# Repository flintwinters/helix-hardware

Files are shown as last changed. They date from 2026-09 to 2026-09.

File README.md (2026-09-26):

# Helix minimal hardware slice

KiCad 10 schematic for a USB powered STM32C071FBP6 with one shared SPI bus. The WIZ850io W5500 module and a **3.3 V, six wire microSD SPI breakout** have separate chip selects. SWD is available for first firmware bring-up.

Open `helix_minimal.kicad_pro` in KiCad. Run `python3 manage.py check` for label lint, ERC, and critical nets, or `python3 manage.py audit` for full DRC and every PCB pad net. The [PCB audit](docs/pcb_audit.md) records datasheet mappings and remaining risks. `python3 manage.py repair` fixes misplaced component reference/value fields in the existing schematic without rebuilding it. `python3 manage.py build` creates a schematic only when none exists. Building needs the KiCad 10 symbol library (`KICAD_SYMBOL_DIR` can point to it); the checked-in schematic and local symbols are self-contained.

## PCB routing

The PCB uses pinned [KiCadRoutingTools](https://github.com/drandyhaas/KiCadRoutingTools) (`git submodule update --init`). USB D+/D− were routed manually; the other signals were autorouted around them. Board Setup specifies 0.30 mm tracks and 0.20 mm clearance for ordinary nets. The USB connector class uses 0.15 mm tracks and clearance for USB D±, CC1/CC2, and VBUS; cross-class clearance is 0.20 mm. GND has F.Cu and B.Cu pours, with no GND tracks or vias. Both pours use thermal reliefs by default: in KiCad's [zone format](https://dev-docs.kicad.org/en/file-formats/sexpr-intro/index.html), omitting the `connect_pads` mode selects thermal reliefs, while `yes` selects solid connections. The four mounting-hole pads remain solid for mechanical grounding. Seven crowded GND pads use explicit solid connections because thermal reliefs there left only one spoke and failed DRC.

After manually connecting `/USB_DP` and `/USB_DM`, run `python3 manage.py route` on a preserved board. It removes other top-level tracks and vias from a working copy while retaining the manual USB copper, footprints, and both GND zones. It refuses to start until both USB data nets have copper, excludes them and GND from every autorouter net list, and verifies that their copper geometry survives the route. It routes CC1/CC2/VBUS first at 0.15 mm width, then SWCLK and the other ordinary nets at 0.30/0.20 mm. The USB pass omits `--clearance` so the router honors the 0.20 mm clearance against ordinary nets. It force-reroutes SPI MISO at 0.30 mm to remove the router's multipoint narrow taper, then force-reroutes +3V3 to remove a dangling via observed in the earlier 4000 turn-cost run. All passes use `--via-cost 300 --turn-cost 4000 --heuristic-weight 1.0 --same-net-pad-clearance 0.1 --grid-step 0.05 --via-size 0.4 --via-drill 0.2 --escalation off --strict-sizes --no-fix-drc-settings`. The router tries direction-preference costs 1200 and 2000 (F.Cu horizontal, B.Cu vertical), then installs the completed route with the smallest sum of squared non-USB net lengths plus an off-axis penalty. The original and intermediate boards remain in `.recovery/`. This is candidate selection; the pinned Rust A* search itself has no quadratic-length parameter. Run `python3 manage.py audit` after routing.

KiCad DRC reports no signal routing or thermal-relief violations and zero schematic parity issues. Two GND connections remain for manual review; 18 text-height warnings remain. The WIZ850io module body overlaps H3, R3, and R4 in a mechanical courtyard probe; resolve its assembly height and mechanical clearance before fabrication. J6 has SWCLK where an SPI accessory would need SCK.

The current route uses a 4000 turn cost and direction-preference cost 2000. All 24 manually drawn USB data copper items were preserved exactly. Its input and intermediate boards are recoverable in `.recovery/` if needed.

## Interfaces

| Interface | STM32 pads | Connector pins |
| --- | --- | --- |
| SPI1 SCK / MISO / MOSI | PA5 / PA6 / PA7 | WIZ850io U3.4 / U3.7 / U3.3; microSD J4.5 / J4.3 / J4.4 |
| W5500 select / interrupt / reset | PA4 / PA3 / PA0 | WIZ850io U3.5 / U3.6 / U3.8 |
| microSD select | PA8 | J4.6 |
| USB D− / D+ | PA11 / PA12 | J1 A7+B7 / A6+B6 |
| SWDIO / SWCLK / NRST | PA13 / PA14 / PF2 | J5.2 / J5.3 / J5.5 |

J4 is a **project-defined jumper header**, not a claimed footprint for a particular SD module: 1=GND, 2=3V3, 3=SO/MISO, 4=SI/MOSI, 5=CLK, 6=CS. Check the chosen breakout's physical pin order before wiring it. U3 combines WIZ850io J1 pins 1–6 with J2 pins 6–1 as footprint pads 1–12. Its board placement remains subject to DRC and mechanical review. Firmware should hold WIZ_RST low for at least 500 µs, then wait 50 ms after release before SPI access. Keep both CS lines high while neither device is selected.

The USB-C receptacle uses separate 5.1 kΩ CC pull-downs and a 3.3 V AP2112K regulator. C1 and C2 are the regulator's required 1 µF input/output capacitors; C3 is the MCU's 100 nF decoupling capacitor. VBUS, +3V3, and GND use KiCad power symbols connected by wires. There is no enclosure, firmware, USB ESD protection, or measured power budget. WIZ850io can draw about 141 mA by itself, so USB bus power behavior before configuration needs design review before claiming USB compliance.

## Source catalog

| Part | Local document | Verified design facts |
| --- | --- | --- |
| [STM32C071FBP6](https://www.st.com/resource/en/datasheet/stm32c071fb.pdf) | Official ST PDF linked; ST download endpoint timed out here | TSSOP20 pinout, SPI1 PA5/6/7, USB PA11/12, 2–3.6 V supply |
| [WIZ850io](https://docs.wiznet.io/Product/ioModule/WIZ850io) / [W5500](https://docs.wiznet.io/assets/files/W5500_ds_v110e-226ffec190c588b69f88d629789585e1.pdf) | `docs/wiz850io_schematic.pdf`, `docs/w5500.pdf` | 3.3 V module; two 1×6 headers; reset timing; about 141 mA normal operating current |
| [WIZ850io KiCad library](https://github.com/lorenzofattori/WIZ850io-KiCad-library) | `vendor/wiz850io/WIZ850io.lib`, `vendor/wiz850io/WIZ850io.kicad_sym`, `footprints/Helix.pretty/WIZ850io.kicad_mod` | Imported 12-pad symbol/footprint; 20.32 mm row spacing and 2.54 mm pitch match the module drawing. Socket pad drill enlarged from 0.762 to 1.0 mm to match the prior KiCad pin-socket footprints; module outline moved from silk to fabrication layer for clearance. Library is third-party; verify the actual module revision and mating socket before fabrication. |
| [AP2112K-3.3](https://www.diodes.com/datasheet/download/AP2112.pdf) | `docs/ap2112.pdf` | SOT-23-5, 600 mA rating, 1 µF input/output ceramic capacitors |
| [GCT USB4110](https://gct.co/files/specs/usb4110-spec.pdf) | `docs/usb4110.pdf` | USB 2.0 Type-C receptacle footprint and contact arrangement |
| [Adafruit 3 V microSD breakout guide](https://learn.adafruit.com/adafruit-microsd-spi-sdio/pinouts) | `docs/adafruit_microsd_breakout.pdf` | 3.3 V-only SPI signals; generic J4 follows signal names rather than its physical header order |

The local `Helix:AP2112K-3.3` symbol is the KiCad 10 library's inherited AP2112K symbol flattened for portability. The edited STM32 pin layout is stored in `symbols/STM32C071FBPx.kicad_sym`. The WIZ850io symbol was converted from the linked KiCad library with `kicad-cli sym upgrade`; its footprint was upgraded with `kicad-cli fp upgrade`. Other symbols come from the installed KiCad library.

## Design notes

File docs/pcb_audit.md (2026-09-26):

# PCB electrical and footprint audit — 2026-09-26

Run `python3 manage.py audit` after schematic or PCB changes. It runs the project checks and ERC, then KiCad DRC with zone refill, all track errors, all severities, and schematic parity. It compares every PCB pad net with the exported schematic netlist. The report is `.recovery/audit/drc_all.txt`. This comparison checks connectivity, not whether a chosen physical module has the same header order.

## Verified pad maps

| Ref | Datasheet comparison | Result |
| --- | --- | --- |
| U1 STM32C071FBP6, TSSOP20 | ST DS14693 TSSOP20 figure and alternate-function table: 4 VDD, 5 VSS, 6 PF2/NRST, 7 PA0, 10 PA3, 11 PA4, 12 PA5/SPI1_SCK, 13 PA6/SPI1_MISO, 14 PA7/SPI1_MOSI, 15 PA8, 16 PA11/USB_DM, 17 PA12/USB_DP, 18 PA13/SWDIO, 19 PA14/SWCLK, 20 PB6 by reset-default pin mux. | Matches schematic and footprint. PB6 is used as PICO_CS; firmware must retain its PB6 mux selection. |
| U2 AP2112K-3.3, SOT-23-5 | Diodes AP2112: 1 VIN, 2 GND, 3 EN, 4 NC, 5 VOUT; 1 µF input and output ceramic capacitors. | Matches. EN is tied to VBUS. C1 and C2 are present. |
| U3 WIZ850io | WIZnet: J1 pins 1–6 = GND, GND, MOSI, SCLK, SCSn, INTn; J2 pins 1–6 = GND, 3V3, 3V3, NC, RSTn, MISO. Footprint pads 1–6 map J1.1–6; pads 7–12 map J2.6–1. Header pitch 2.54 mm and row spacing 20.32 mm match the vendor dimension drawing. | Matches schematic and module pinout. Shared SPI MISO is valid while deselected: W5500 MISO is high impedance when SCSn is high. |
| J1 GCT USB4110 | GCT drawing: A5/B5 CC1/CC2, A6/B6 D+, A7/B7 D−, A4/A9/B4/B9 VBUS, A1/A12/B1/B12 GND; shell GND. | All contact numbers match. Shell pad SH is one of the remaining GND opens. |
| J4 microSD, J5 SWD | Project-defined 1×6 microSD header = GND, 3V3, MISO, MOSI, SCK, CS. Project-defined 1×5 SWD header = 3V3, SWDIO, SWCLK, GND, NRST. | PCB and schematic agree. J4 has no selected module part number, so its *physical* header pin order cannot be certified. Verify the actual breakout before connecting it. |
| R1–R6, C1–C3 | Passive nets agree with schematic. C1's two pads are opposite the old `manage.py` build template, but a nonpolar ceramic capacitor has no electrical polarity. | Current board agrees with current schematic. Footprints have combined 0805 SMD and PTH pads with duplicate pad numbers; assembly method and chosen parts need review. |

Sources: [ST STM32C071 datasheet](https://www.st.com/resource/en/datasheet/stm32c071gb.pdf), [ST RM0490 pin mux](https://www.st.com/resource/en/reference_manual/rm0490-stm32c0-series-advanced-armbased-32bit-mcus-stmicroelectronics.pdf), [Diodes AP2112](https://www.diodes.com/datasheet/download/AP2112.pdf), [WIZ850io pinout](https://docs.wiznet.io/Product/ioModule/WIZ850io), [WIZ850io mechanical drawing](https://docs.wiznet.io/img/products/wiz850io/wiz850io_dimension.png), [GCT USB4110 drawing](https://gct.co/files/drawings/usb4110.pdf), [Adafruit 3 V microSD pinout example](https://learn.adafruit.com/adafruit-microsd-spi-sdio/pinouts).

## Findings that still require a design decision

1. **J6 function conflict:** J6 is named `pico hdmi` and carries MOSI, MISO, PICO_CS, GND, and **SWCLK** on pin 5. It has no SPI SCK or 3V3. PA14/SWCLK has no SPI1_SCK alternate function, so J6 cannot act as a standard SPI peripheral header as wired. Debug clock activity will also reach J6. Decide J6's intended device and pinout before using it. The MCU's main WIZ850io and SD SPI pins have no such conflict.
2. **WIZ850io physical overlap is hidden from normal DRC:** U3 has no F.CrtYd, and `missing_courtyard` is ignored in project rules. A disposable DRC probe using the vendor's 23×25 mm body and jack projection as a courtyard found overlap with H3, R3, and R4, including H3 and four resistor PTH pads inside that footprint. The module may clear the resistors if mounted on tall sockets, but H3 hardware and underside clearance depend on actual assembly height. Verify socket and screw hardware, then add an assembly-appropriate courtyard and relocate conflicts before fabrication. The RJ45 projection also reaches about 0.94 mm beyond the top board edge; check enclosure clearance.
3. **Ground:** Full DRC reports two open GND connections: J1 shell pad SH and an isolated F.Cu GND zone island. Both were left for manual resolution. All other signals pass copper clearance checks.
4. **Power and USB behavior:** WIZ850io is about 141 mA in normal operation and U2 EN follows VBUS, so the Ethernet module powers immediately. Confirm the intended USB bus power behavior before claiming compliance. The USB pair has about 0.09 mm length difference, but board stackup and differential impedance have not been specified or measured.
5. **Assembly data:** R1–R6 and C1–C3 lack manufacturer part numbers, so nominal 0805 package compatibility and the unusual SMD/PTH combination cannot be fully certified. U3's third-party footprint should be matched against the received module/socket revision. The input and output regulator capacitors are present but roughly 10–12 mm from U2; review placement against the regulator's layout guidance.

Baseline full DRC: 2 GND opens, 18 silk text-height warnings, 0 footprint errors, 0 schematic parity errors, and no signal routing clearance violations. The ERC has 0 errors and one known J1 library-symbol mismatch warning caused by the user-edited embedded symbol. These counts do not prove mechanical fit, signal integrity, or USB power compliance.

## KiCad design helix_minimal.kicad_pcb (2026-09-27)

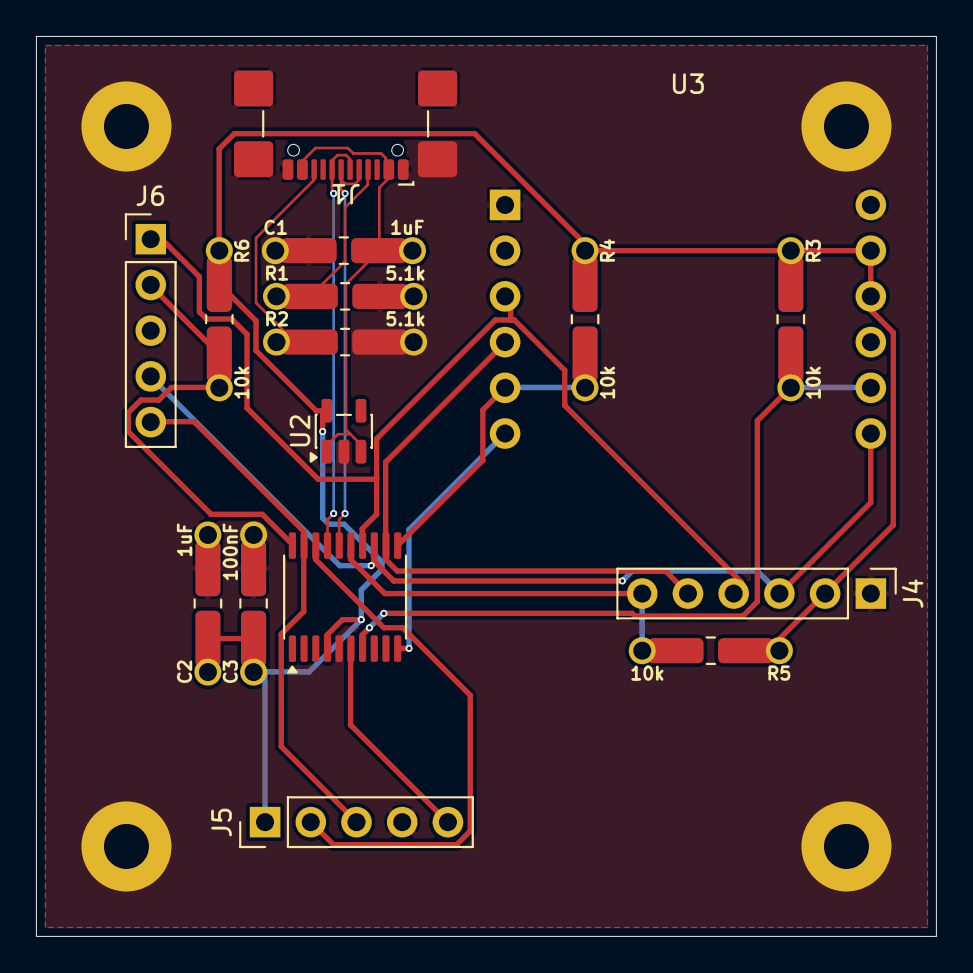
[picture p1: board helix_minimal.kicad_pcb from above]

Board: 2 copper layers, 50.0 x 50.0 mm, 20 parts (0 on the bottom side), 18 nets.

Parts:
C1, C2: 1uF; R_0805_2012Metric_Pad1.20x1.40mm_HandSolder
C3: 100nF; R_0805_2012Metric_Pad1.20x1.40mm_HandSolder
H1, H2, H3, H4: MountingHole_Pad; MountingHole_2.5mm_Pad
J1: USB-C; USB_C_Receptacle_GCT_USB4110
J4: sd card; PinHeader_1x06_P2.54mm_Vertical
J5: SWD; PinHeader_1x05_P2.54mm_Vertical
J6: pico hdmi; PinHeader_1x05_P2.54mm_Vertical
R1, R2: 5.1k; R_0805_2012Metric_Pad1.20x1.40mm_HandSolder
R3, R4, R5, R6: 10k; R_0805_2012Metric_Pad1.20x1.40mm_HandSolder
U1: STM32C071FBP6; TSSOP-20_4.4x6.5mm_P0.65mm
U2: AP2112K-3.3; SOT-23-5
U3: WIZ850io

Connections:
+3V3: C2.1, C3.1, J4.2, J5.1, R3.1, R4.1, R5.1, R6.1, U1.4 (VDD), U2.5 (VOUT), U3.10 (3.3V), U3.11 (3.3V)
/CC1: J1.A5 (CC1), R1.1
/CC2: J1.B5 (CC2), R2.1
/NRST: J5.5, U1.6 (PF2)
/PICO_CS: J6.2, R6.2, U1.20 (PB3/PB4/PB5/PB6)
/SD_CS: J4.6, R5.2, U1.15 (PA8)
/SPI_MISO: J4.3, J6.4, U1.13 (PA6), U3.7 (MISO)
/SPI_MOSI: J4.4, J6.1, U1.14 (PA7), U3.3 (MOSI)
/SPI_SCK: J4.5, U1.12 (PA5), U3.4 (SCLK)
/SWCLK: J5.3, J6.5, U1.19 (PA14/PA15)
/SWDIO: J5.2, U1.18 (PA13)
/USB_DM: J1.A7 (D-), J1.B7 (D-), U1.16 (PA11)
/USB_DP: J1.A6 (D+), J1.B6 (D+), U1.17 (PA12)
/WIZ_CS: R4.2, U1.11 (PA4), U3.5 (SCNn)
/WIZ_INT: U1.10 (PA3), U3.6 (~INTn)
/WIZ_RST: R3.2, U1.7 (PA0), U3.8 (~RST)
GND: C1.1, C2.2, C3.2, H1.1 (1_1), H2.1 (1_1), H3.1 (1_1), H4.1 (1_1), J1.A1 (GND), J1.A12 (GND), J1.B1 (GND), J1.B12 (GND), J1.SH (SHIELD), J4.1, J5.4, J6.3, R1.2, R2.2, U1.5 (VSS), U2.2 (GND), U3.1 (GND), U3.2 (GND), U3.12 (GND)
VBUS: C1.2, J1.A4 (VBUS), J1.A9 (VBUS), J1.B4 (VBUS), J1.B9 (VBUS), U2.1 (VIN), U2.3 (EN)

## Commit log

2026-09-26 Add minimal STM32 USB Ethernet SD KiCad schematic
    [helix_minimal.kicad_sch]
2026-09-26 Ignore generated KiCad history and Python cache
2026-09-26 Space schematic labels and verify all interface nets
    [helix_minimal.kicad_sch]
2026-09-26 Add protected buck supply and switched peripheral rail
    [helix_minimal.kicad_sch]
2026-09-26 Simplify power wiring to explicit supply symbols
    [helix_minimal.kicad_sch]
2026-09-26 Lint schematic component label placement
    [helix_minimal.kicad_sch]
2026-09-26 Align STM32 connections with edited symbol
    [helix_minimal.kicad_sch]
2026-09-26 Restore KiCad edits and guard schematic generation
    [helix_minimal.kicad_sch]
2026-09-26 Separate safe schematic repair from fresh build
2026-09-26 Make repair regression test accept KiCad formatting
2026-09-26 Use WIZ850io module symbol and sourced footprint
    [helix_minimal.kicad_pcb, helix_minimal.kicad_sch]
2026-09-26 Route PCB with fixed fine-pitch rules
    [helix_minimal.kicad_pcb]
2026-09-26 Reroute PCB without in-pad vias and widen copper
    [helix_minimal.kicad_pcb]
2026-09-26 Reroute board with hard 0.30 mm ordinary traces
    [helix_minimal.kicad_pcb]
2026-09-26 Use dual ground pours and route signals with higher via cost
    [helix_minimal.kicad_pcb]
2026-09-26 Increase router turn penalty and reroute signal copper
    [helix_minimal.kicad_pcb]
2026-09-26 Route USB signals first and retain project rules
    [helix_minimal.kicad_pcb]
2026-09-26 Use thermal reliefs on ground pours
    [helix_minimal.kicad_pcb]
2026-09-26 Clear copper and preserve manual USB data routes
    [helix_minimal.kicad_pcb]
2026-09-26 Route around manual USB data pair and preserve schematic edits
    [helix_minimal.kicad_pcb, helix_minimal.kicad_sch]
2026-09-26 Add repeatable full PCB audit and document footprint findings
2026-09-26 Reroute signals with stronger layer direction preference and quadratic route selection
    [helix_minimal.kicad_pcb]
2026-09-26 Install rerouted board after quadratic candidate selection
    [helix_minimal.kicad_pcb]
